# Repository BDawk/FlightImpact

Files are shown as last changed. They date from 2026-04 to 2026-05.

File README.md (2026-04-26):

# FlightImpact

A custom golf launch monitor combining computer vision (high-speed camera) with Doppler radar (HB100), targeting within 5% accuracy of industry standard launch monitors.

## Repository layout

```
flightimpact/
├── core/        Reusable algorithms, models, and API contract — ships in production
├── app/         Progressive Web App — runs on phone, tablet, desktop browser
├── devkit/      Dev kit code — Pi 5 services, Uno firmware, breadboard config
├── hardware/    Schematics, BOMs, 3D-printable mounts (currently dev kit only)
└── docs/        Architecture, setup, calibration, API reference
```

The rule: **`core/` and `app/` never import from `devkit/`.** When the production
hardware is ready, a new top-level folder will be created (`production/`) that also
imports from `core/`. The dev kit becomes one of multiple frontends to the same
algorithm core.

## Quick start (dev kit)

See [`docs/devkit_setup.md`](docs/devkit_setup.md) for the full guide. TL;DR:

```bash
# On the Raspberry Pi 5
cd devkit/pi
pip install -e ".[dev]"
python -m flightimpact_devkit.api

# In a separate terminal — build and serve the app
cd app
npm install
npm run dev
```

Then open `http://flightimpact.local:5173` from any device on the same network.

## Architecture

See [`docs/architecture.md`](docs/architecture.md).

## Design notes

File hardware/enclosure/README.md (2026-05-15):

# Enclosure (Second Pass)

This enclosure is now a horizontal rounded-rectangle chassis with:

- Side-by-side internal bays for battery + Pi 5 stack
- Pi 5 mounting on M2.5 heat-set insert bosses
- Top screen window + pocket + retention clamps
- PiSugar external interface holes (two button channels)
- External USB-C charging window
- Removable side service lid with 4x M3 screws

## Files

- `params.scad`: all tunable dimensions
- `base.scad`: main body
- `lid.scad`: removable service lid (print separately)
- `dock.scad`: legacy docking rail interface (disabled by default)

## Critical Tune-First Parameters

These are intentionally parameterized because exact modules vary by vendor revision:

- Screen:
  - `SCREEN_ACTIVE_W`, `SCREEN_ACTIVE_H`
  - `SCREEN_MODULE_W`, `SCREEN_MODULE_H`, `SCREEN_MODULE_T`
  - `SCREEN_POCKET_CLR`
- PiSugar button alignment:
  - `PISUGAR_BTN_Y`, `PISUGAR_BTN_Z1`, `PISUGAR_BTN_Z2`
  - `PISUGAR_BTN_HOLE_D`, `PISUGAR_BTN_GUIDE_ID`
- External charging breakout:
  - `CHARGE_PORT_W`, `CHARGE_PORT_H`, `CHARGE_PORT_X`, `CHARGE_PORT_Z`

## Pi Mounting / Inserts

Pi bosses are sized for M2.5 heat-set inserts:

- `PI_INSERT_OD`
- `PI_INSERT_DEPTH`
- `PI_BOSS_OD`

Recommended process:

1. Print only a small boss test coupon using your insert brand.
2. Confirm press-fit and melt depth.
3. Adjust `PI_INSERT_OD` in 0.1 mm increments as needed.

## Notes

- `ENABLE_DOCK = false` by default to keep the top surface dedicated to screen integration.
- If you need dock rails again, set `ENABLE_DOCK = true` in `params.scad`.

## Suggested Validation Workflow

1. Print a low-infill draft of `base.scad` at 0.28 mm layer height.
2. Dry-fit battery, Pi, PiSugar stack, and screen module.
3. Measure offsets and update only `params.scad`.
4. Reprint final with production wall/infill.

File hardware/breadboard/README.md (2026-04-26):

# HB100 amplifier — breadboard build

The HB100 produces a tiny IF signal — typically a few hundred microvolts to
a few millivolts. Before any ADC can sample it usefully, it needs ~60–80 dB
of gain plus high-pass filtering to get rid of the DC bias.

## Two-stage topology

```
         +---------------+        +---------------+
HB100 IF─┤ Stage 1       ├────────┤ Stage 2       ├──→ Line out
         │ LM358         │        │ TL072         │     (to ADC / sound card)
         │ Gain ≈ 100×   │        │ Gain ≈ 50×    │
         │ HPF fc=20 Hz  │        │ LPF fc=8 kHz  │
         +---------------+        +---------------+
         total gain ≈ 5000× (74 dB)
         passband ≈ 20 Hz – 8 kHz
```

The HPF in stage 1 removes the DC offset and 1/f noise. The LPF in stage 2
brick-walls the band of interest — golf Doppler returns sit between roughly
200 Hz (slow club approach) and 5500 Hz (driver ball flight).

## Component values

Pick values for non-inverting amplifier topology:
- **Stage 1 (LM358)**: Rf = 100k, Ri = 1k → gain = 101
  - HPF: input cap 1 µF + 8.2k bias resistor → fc ≈ 20 Hz
- **Stage 2 (TL072)**: Rf = 47k, Ri = 1k → gain = 48
  - LPF: feedback cap 470 pF across Rf → fc ≈ 7.2 kHz

## Power

Run the amps on a 9V battery, not the Pi 5V rail. The Pi rail is full of
switching noise that ends up in your audio band as a constant ~kHz hum.
Use a 78L05 to derive 5V for the HB100 itself, but keep the op-amp rails
isolated.

## Grounding

Star-ground at the battery negative. The HB100 ground, both op-amp grounds,
the output cable shield, and the bias network all return to the same physical
node. Don't daisy-chain.

## Shielding

The 10.525 GHz radiation from the HB100 will couple back into your amplifier
inputs if they're long traces on a breadboard. Keep stage-1 input wires under
2 cm. Once the rig works, build it on a small piece of perf board with a
ground plane underneath — this is the single biggest noise reduction you can
make.

## What to expect

With no target moving, you should see ~50 mV peak-to-peak of broadband noise
on a scope at the output. Wave your hand a foot away from the HB100 and you
should see a ~500 mV burst at a few hundred Hz. If you don't, check:
- HB100 powered from 5V (not 9V — it'll work but get hot)
- Op-amp pin 1 wired correctly (the LM358 pinout is non-obvious — pin 1 is
  output A, not input A)
- Battery actually connected (yes, this is the most common failure mode)

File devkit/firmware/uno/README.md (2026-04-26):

# Uno R3 firmware

The Uno acts as the dev kit's hardware-timing front-end:

| Pin  | Function |
|---|---|
| D8 | Hardware trigger output (5 V pulse, ~100 µs) — wire to camera shutter sync or strobe driver |
| D9 | LED strobe PWM output — wire to a MOSFET gate driving an LED array |
| D13  | Onboard heartbeat LED |

## Flashing

1. Open `uno.ino` in the Arduino IDE
2. Select board: **Arduino Uno**
3. Select port: the `/dev/ttyACM*` (Linux/macOS) or `COMx` (Windows) the Uno appears on
4. Click Upload

Or with `arduino-cli`:

```bash
arduino-cli compile --fqbn arduino:avr:uno uno.ino
arduino-cli upload  --fqbn arduino:avr:uno --port /dev/ttyACM0 uno.ino
```

## Testing without the Pi

Open a serial monitor at 115200 baud and try:

```
PING        -> PONG
ID          -> FLIGHTIMPACT-DEVKIT v0.1
TRIG        -> OK   (and you should see a pulse on D8)
STROBE 200  -> OK   (D9 HIGH for 200 ms)
STROBE OFF  -> OK
```

## Phase 2 plans

Replace the simple text protocol with a binary frame protocol that streams
HB100 IF samples to the Pi at 20 kHz. The header (`magic + n_samples`) is
already documented in `flightimpact_devkit/hal/hb100_radar.py::SerialRadar`.

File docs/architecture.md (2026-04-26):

# Architecture

FlightImpact splits cleanly into three layers: **algorithm core**, **device-side
services**, and **client app**. The core ships in both the dev kit and (eventually)
the production unit; the device services wrap the core in hardware-specific glue;
the app talks to the device over a versioned API contract.

## Repository layout in one paragraph

`core/` holds the reusable algorithms (radar DSP, ball detection, tracking,
spin extraction, ballistics), Pydantic data models, and the API contract.
`app/` is the React PWA — same code on phone, tablet, desktop browser. `devkit/`
contains everything that's specific to the dev-kit hardware: Pi 5 services
(`devkit/pi/`), Uno R3 firmware (`devkit/firmware/uno/`), and the Pi-only setup
scripts and systemd units. Hardware schematics and BOMs live in `hardware/`.
The dev kit imports from core; core never imports from the dev kit.

## Data flow — from photons to phone

1. The **HB100** emits a 10.525 GHz CW signal. Reflections from the clubhead
   and ball mix down to an audio-frequency IF signal proportional to radial
   velocity. The two-stage LM358 / TL072 amplifier brings this from microvolts
   to a clean line-level signal the Pi (or Uno) can sample.

2. The **camera** runs at 1080p120 in MJPEG, dumping frames to a userspace ring
   buffer in the camera service. The ring is sized to hold ~2 seconds of
   history so we have pre-impact frames available the moment a trigger fires.

3. The **radar service** continuously runs FFT on incoming sample blocks,
   extracts the dominant Doppler peak, and watches for a peak above the
   trigger threshold. When the clubhead approach pushes the speed estimate
   above ~30 mph (configurable), it fires a trigger callback.

4. The **processor service** receives the trigger, waits the post-trigger
   window for the ball to fly through frame, snapshots both the camera ring
   buffer and the radar sample buffer, and runs the analysis pipeline.

5. The pipeline runs ball detection → ball tracking → club detection →
   spin extraction → sensor fusion → ballistics simulation, producing a
   `ShotMetrics` object with per-metric confidence values.

6. Results are persisted to SQLite and pushed to all connected clients via
   the WebSocket as `ShotUpdated` messages. The same socket carries device
   status heartbeats, optional live camera previews, and optional radar
   spectrum frames for the dev waterfall view.

## Why this split

Three forces drove the structure:

**Hardware will change.** Production units will not use a USB camera or a
breadboard radar. By keeping algorithms in `core/` and hardware glue in
`devkit/pi/hal/`, the production firmware can implement the same `CameraSource`
and `RadarSource` protocols and reuse every line of algorithm code.

**The app should not know which device it's talking to.** Dev kit and
production unit speak the same versioned REST + WebSocket contract. Same PWA
build can target either.

**Iteration speed during development.** Python on the Pi means the entire
CV/DSP stack runs in one process with no marshaling — OpenCV, NumPy, SciPy,
Pydantic all native. When something is too slow, profile and selectively port
hot paths to C++ via pybind11 — don't rewrite the world up front.

## Connectivity model

The Pi runs in either of two modes, switchable at runtime:

- **AP mode (default)**: Pi creates its own Wi-Fi hotspot. Phone connects
  directly with no router involved. This is what you use at the range, in the
  backyard, anywhere with no infrastructure.
- **Client mode**: Pi joins an existing Wi-Fi network. Used at home for OTA
  updates and (later) cloud sync.

Both modes serve the app at `http://flightimpact.local:8000` via mDNS, so you
never type IP addresses.

## Versioning

The API contract is versioned in `core/api_contract/__init__.py`. Bumping
`API_VERSION` is a breaking-change signal for clients. The TypeScript types in
`app/src/lib/types.ts` are kept in sync by hand for now; the future plan is to
generate them from FastAPI's OpenAPI spec at build time.

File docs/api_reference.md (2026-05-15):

# API reference

The dev kit exposes a versioned REST + WebSocket API. The same contract will
be implemented by production firmware, so anything you build against this
will keep working.

Base URL: `http://flightimpact.local:8000` (or `http://192.168.4.1:8000` in
AP mode).

## REST endpoints

All paths under `/api/v1/`. Responses are JSON.

### `GET /api/v1/version`
Returns `{api_version, service}`. Use this for compatibility detection.

### `GET /api/v1/status`
Returns the current `DeviceStatus`. Same shape as the periodic WS heartbeat.

### `GET /api/v1/shots?limit=50&offset=0`
List recent shots, newest first.

### `GET /api/v1/shots/{id}`
Single shot by UUID. Returns `404` if not found.

### `POST /api/v1/shots/{id}/notes`
Body: `{notes?, club?}`. Update freeform notes or club tag for an existing
shot. Returns the updated `Shot`.

### `POST /api/v1/test/trigger`
Manually fire a test shot. Returns the shot stub immediately; the final
metrics arrive via WebSocket as the processor finishes. Dev-mode only —
returns `403` in production builds.

### `GET /api/v1/screen/state`
Returns the current on-device screen state snapshot (mode, health flags,
current shot summary, and UI header values).

### `POST /api/v1/screen/mode`
Body: `{mode}` where `mode` is one of `ScreenMode` values. Forces the on-device
screen into that mode. Dev-mode only.

### `POST /api/v1/screen/scenario`
Body: partial scenario payload to update screen state in one call:
`{mode?, boot_progress?, battery_pct?, session_id?, clock_hhmm?, brightness?, shot?}`.
Useful for mockup validation and live scenario testing. Dev-mode only.

## WebSocket

Connect to `/ws`. Messages flow in both directions.

### Server → client

Every message is a JSON object with a `type` discriminator. See
`core/models/telemetry.py` and `app/src/lib/types.ts` for full schemas.

| Type | When | Subscribe needed? |
|---|---|---|
| `device_status` | Every 2s + on-connect | No (default-on) |
| `shot_updated`  | Each transition (capturing → processing → complete) | No |
| `live_frame` | ~10 Hz JPEG preview | Yes |
| `radar_spectrum` | Per FFT block (~20 Hz) | Yes |
| `screen_state`  | On screen-state mutation (mode change, health, shot transition) | No (default-on) |
| `log` | Server log entries | Yes |

### Client → server

Plain text command frames, one per line:

| Command | Effect |
|---|---|
| `subscribe_live_frame` | Start receiving `live_frame` messages |
| `unsubscribe_live_frame` | Stop |
| `subscribe_radar_spectrum` | Start receiving `radar_spectrum` |
| `unsubscribe_radar_spectrum` | Stop |
| `subscribe_logs` | Start receiving `log` messages |
| `unsubscribe_logs` | Stop |
| `subscribe_screen_state` | Start receiving `screen_state` messages |
| `unsubscribe_screen_state` | Stop |

The default-off, opt-in pattern for high-bandwidth streams matters more than
it sounds: a phone on AP-mode Wi-Fi can saturate a 5 GHz link if you stream
1080p MJPEG to it continuously. The app subscribes only when the dev panel
mounts.

## Reconnection

The TypeScript socket client (`app/src/lib/transport/socket.ts`) handles
auto-reconnect with exponential backoff (1s → 8s cap) and replays any pending
subscription commands on each successful reconnect, so a brief Wi-Fi blip
doesn't require user intervention.

## Versioning

`API_VERSION` lives in `core/api_contract/__init__.py`. Bump it on any
breaking change. Clients should fetch `/api/v1/version` on connect and warn
if the major doesn't match.

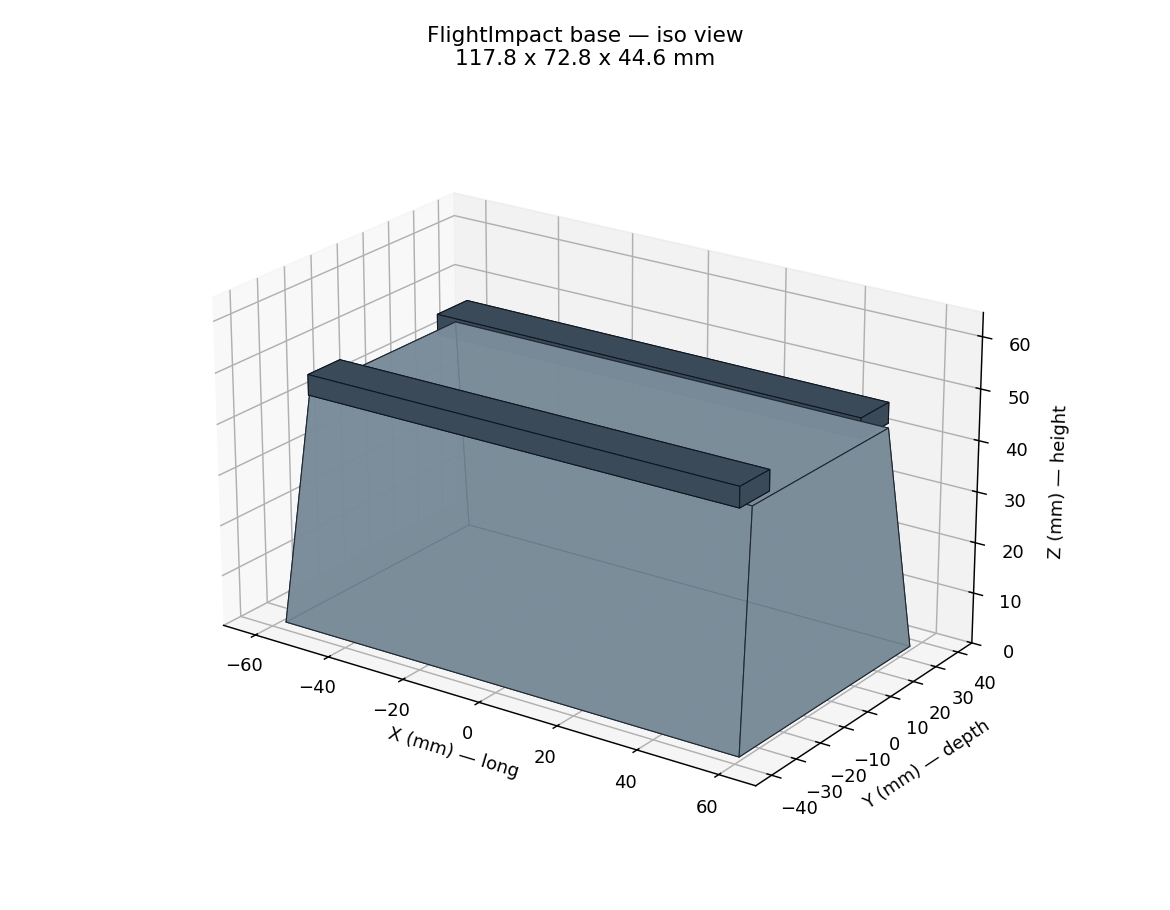
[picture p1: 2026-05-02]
hardware/enclosure/preview/preview_iso.png

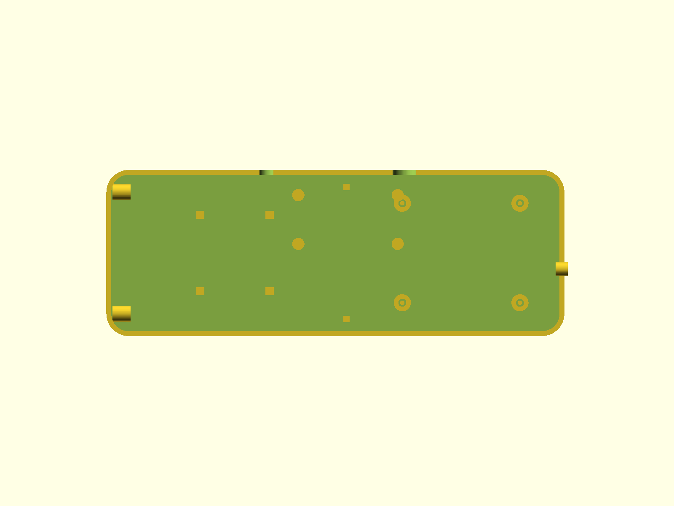
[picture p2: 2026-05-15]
hardware/enclosure/preview/base_top_new.png

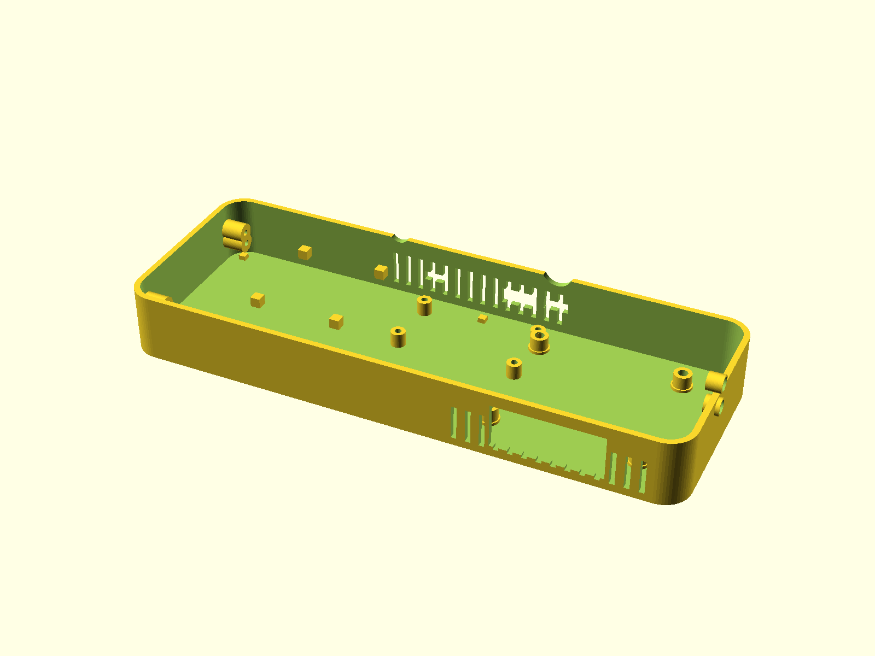
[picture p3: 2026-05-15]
hardware/enclosure/preview/base_default.png

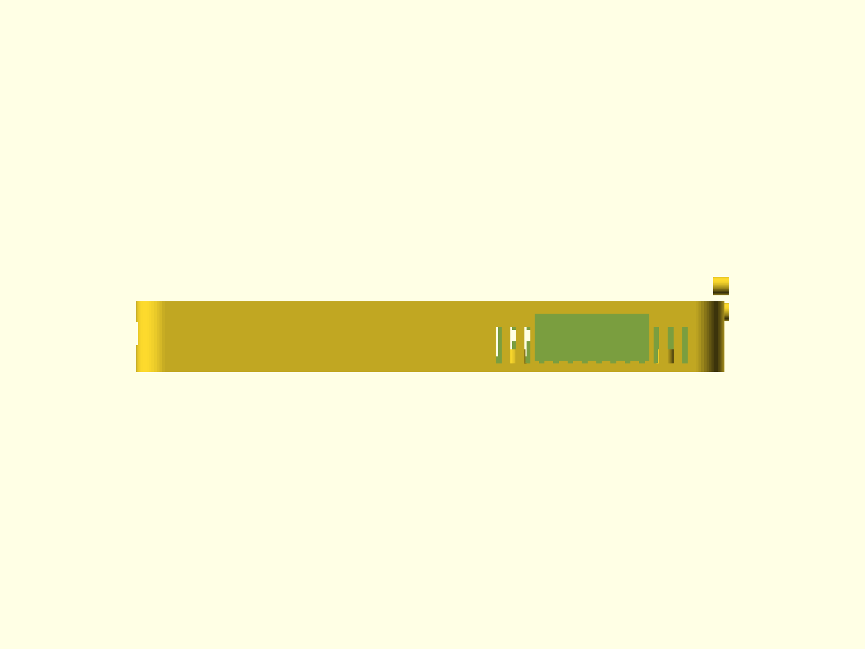
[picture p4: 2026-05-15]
hardware/enclosure/preview/base_front_new.png

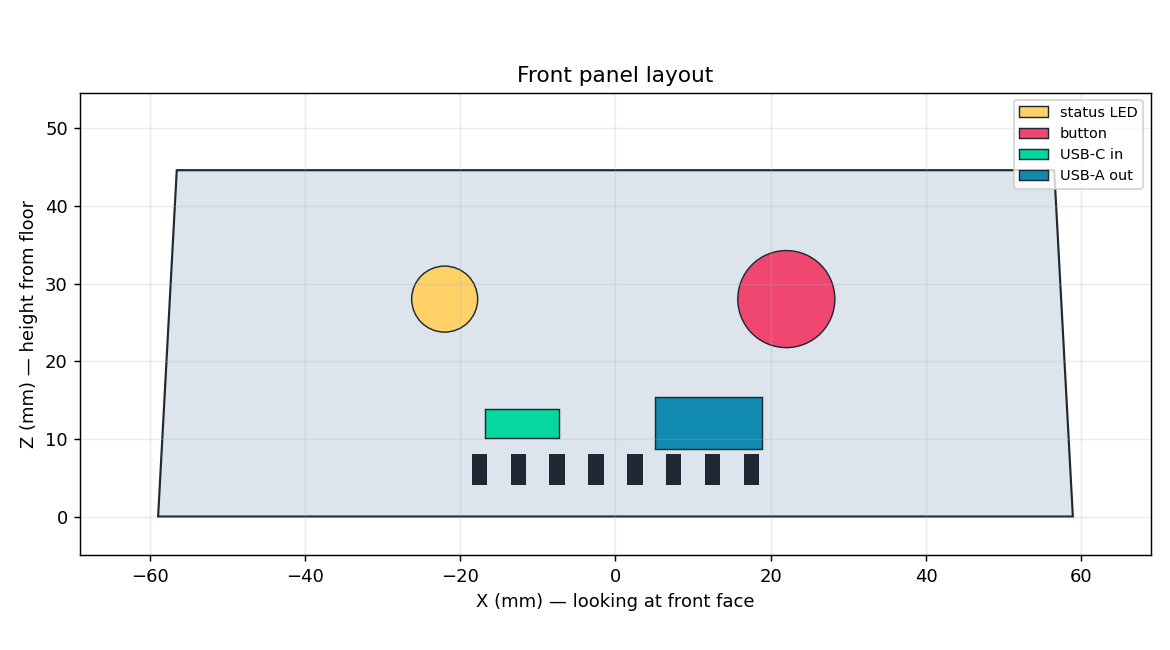
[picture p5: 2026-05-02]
hardware/enclosure/preview/preview_front.png

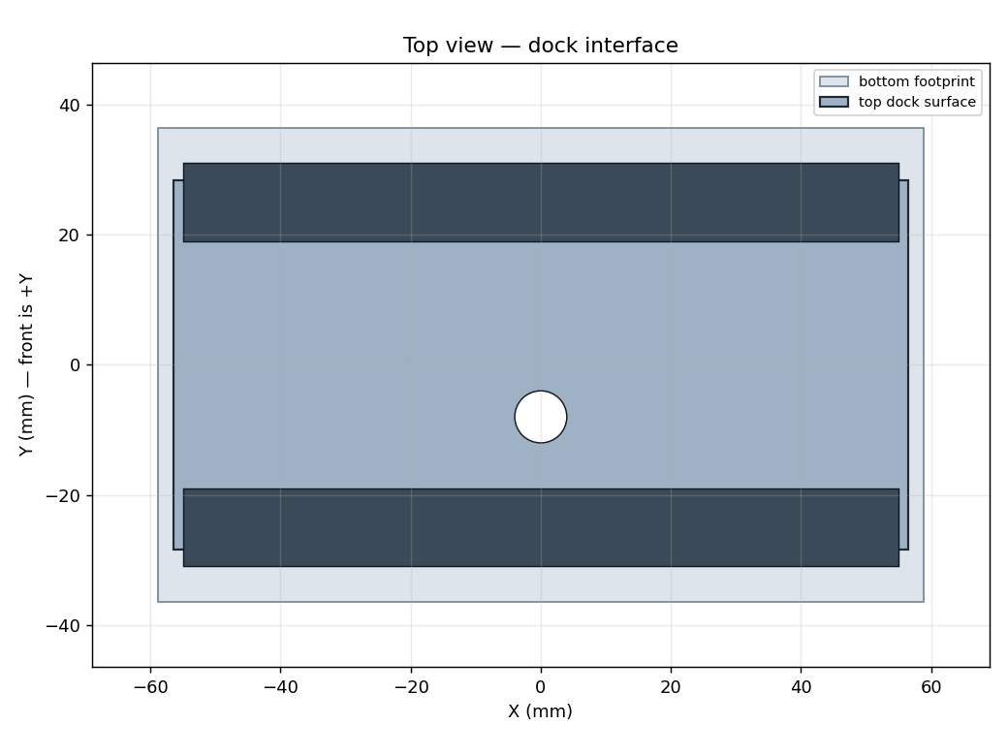
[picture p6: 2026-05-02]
hardware/enclosure/preview/preview_top.png

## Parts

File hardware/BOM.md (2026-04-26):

# Bill of materials — dev kit

Total target: ~$200–$300 in parts, plus the camera you already have.

## Compute

| Item | Qty | Notes |
|---|-----|---|
| Raspberry Pi 5 (4 GB) | 1 | 8 GB if you want headroom |
| Pi 5 active cooler | 1 | Required — Pi 5 throttles fast under sustained load |
| 27W USB-C PD power supply | 1 | The official Pi 5 supply, no substitutes |
| 32 GB A2 microSD | 1 | A2 rating matters — random IOPS during clip writes |
| Elegoo Uno R3 | 1 | Already on hand; trigger + strobe driver |

## Sensing

| Item | Qty | Notes |
|---|-----|---|
| HB100 module | 1 | $5–10 on Amazon / AliExpress |
| Camera (IFWATER 12MP IMX577 25° lens) | 1 | Already on hand |
| USB sound card (CM108-based) | 1 | Cheapest path to ADC for HB100 IF |

Future upgrade for production sensing: global-shutter sensor (Arducam AR0234
1200P or similar) — see `docs/architecture.md` for why.

## HB100 amplifier circuit

| Item | Qty | Notes |
|---|-----|---|
| LM358 dual op-amp DIP-8 | 1 | First stage |
| TL072 dual op-amp DIP-8 | 1 | Second stage (lower noise than LM358 here) |
| Resistors 1%: 10k, 100k, 1M | ~10 each | Gain-setting + biasing |
| Capacitors: 1µF, 10µF (electrolytic), 100nF (ceramic) | ~5 each | DC blocking + decoupling |
| 9V battery + clip | 1 | Cleaner than Pi 5V rail for analog front-end |
| Breadboard (full size, 830 tie-points) | 1 | |
| Jumper wire kit | 1 | M-M, M-F |

See `breadboard/` for the schematic and breadboard layout.

## Mounting + alignment

| Item | Qty | Notes |
|---|-----|---|
| Mini ball-head tripod (camera) | 1 | For repeatable camera positioning |
| Adjustable mount (HB100) | 1 | Doesn't need to be precise — angle calibration handles offset |
| Hitting mat (small turf square) | 1 | Reference position for the ball |
| Alignment laser (optional) | 1 | Cheap line laser makes setup repeatable |

## Cables

| Item | Qty | Notes |
|---|-----|---|
| USB-A to USB-A 2 m | 1 | Camera to Pi |
| USB-A to USB-B | 1 | Uno to Pi |
| 3.5mm TRS shielded | 1 | HB100 amp output to USB sound card line-in |

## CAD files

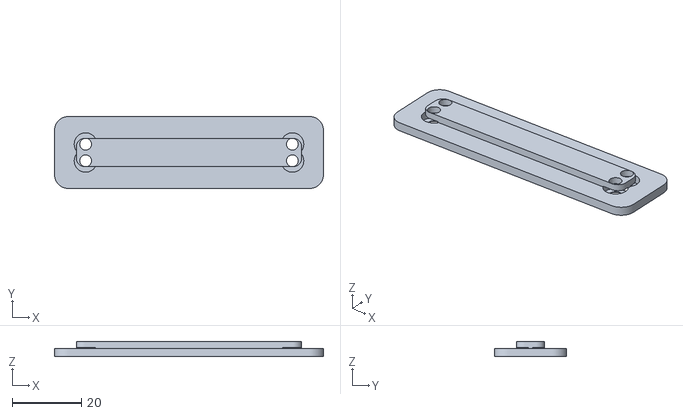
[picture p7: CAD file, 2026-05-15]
hardware/enclosure/lid.stl
77.8 x 20.8 x 4.40

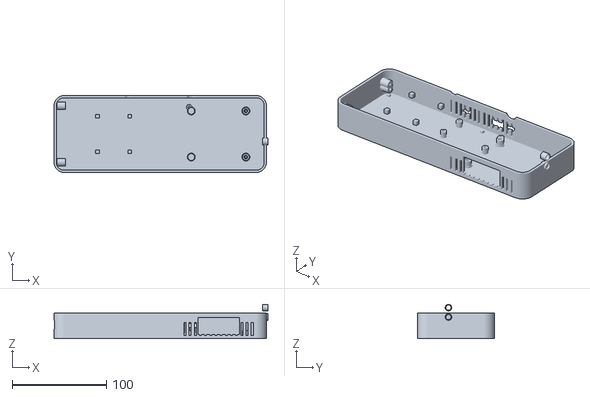
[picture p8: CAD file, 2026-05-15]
hardware/enclosure/base.stl
227.4 x 81.8 x 36.5

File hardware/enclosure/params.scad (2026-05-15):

// FlightImpact enclosure - central parameter file.
// All dimensions in mm.

/* PRINT + GLOBAL TOLERANCE */
$fn = 64;
PRINT_LAYER_H    = 0.2;
PRINT_NOZZLE     = 0.4;
WALL_T           = 2.4;
FLOOR_T          = 2.4;
LID_T            = 2.4;
M3_CLEAR         = 3.4;
M25_CLEAR        = 2.7;
CL_TIGHT         = 0.15;
CL_NORMAL        = 0.30;
CL_LOOSE         = 0.50;

/* RASPBERRY PI 5 */
PI_W             = 85.0;
PI_D             = 56.0;
PI_PCB_T         = 1.6;
PI_HOLE_DX       = 58.0;
PI_HOLE_DY       = 49.0;
PI_STANDOFF_H    = 5.2;
PI_TOP_CLR       = 14.0;

// M2.5 heat-set insert geometry (typical 3.5-4.0mm OD inserts)
PI_BOSS_OD           = 7.2;
PI_INSERT_OD         = 3.9;
PI_INSERT_DEPTH      = 4.8;
PI_INSERT_BOTTOM_WEB = 1.4;

/* BATTERY - single-cell LiPo pack */
BAT_W            = 110.0;
BAT_D            = 65.0;
BAT_H            = 12.0;
BAT_LEAD_LEN     = 60.0;
BAT_BAY_CL       = 1.5;

/* USB CHARGE/DISCHARGE BOARD */
USB_W            = 55.0;
USB_D            = 30.0;
USB_H            = 12.0;
USB_HOLE_DX      = 49.0;
USB_HOLE_DY      = 24.0;

/* STATUS LED / BUTTON */
LED_BEZEL_OD     = 8.5;
LED_NUT_OD       = 11.0;
LED_BODY_LEN     = 18.0;
BTN_HOLE_OD      = 12.5;
BTN_NUT_OD       = 15.0;
BTN_BODY_LEN     = 22.0;

/* SCREEN MODULE - Waveshare 1.69" ST7789V3 (tunable with calipers) */
SCREEN_ACTIVE_W      = 30.6;
SCREEN_ACTIVE_H      = 36.8;
SCREEN_WINDOW_CL     = 0.8;
SCREEN_WINDOW_W      = SCREEN_ACTIVE_W + SCREEN_WINDOW_CL;
SCREEN_WINDOW_H      = SCREEN_ACTIVE_H + SCREEN_WINDOW_CL;
SCREEN_MODULE_W      = 37.5;
SCREEN_MODULE_H      = 41.0;
SCREEN_MODULE_T      = 6.0;
SCREEN_POCKET_CLR    = 0.6;
SCREEN_POCKET_DEPTH  = 2.0;
SCREEN_CLAMP_W       = 4.0;
SCREEN_CLAMP_T       = 2.0;
SCREEN_CLAMP_DROP    = 4.0;

/* PISUGAR 3 PLUS (Pi 5 HAT) - envelope + externalized interface */
PISUGAR_W            = 88.0;
PISUGAR_D            = 58.0;
PISUGAR_H            = 11.5;
PISUGAR_SIDE_CLR     = 2.0;
PISUGAR_BTN_HOLE_D   = 5.2;   // for printed button plungers
PISUGAR_BTN_GUIDE_OD = 7.0;
PISUGAR_BTN_GUIDE_ID = 5.4;
PISUGAR_BTN_Z1       = 23.0;
PISUGAR_BTN_Z2       = 33.0;
PISUGAR_BTN_Y        = -8.0;

/* EXTERNAL CHARGING PORT (panel-mount USB-C breakout) */
CHARGE_PORT_W        = 10.2;
CHARGE_PORT_H        = 4.2;
CHARGE_PORT_X        = 34.0;
CHARGE_PORT_Z        = 14.0;

/* SIDE LID FASTENING */
LID_SCREW_D          = M3_CLEAR;
LID_SCREW_HEAD_D     = 6.6;
LID_SCREW_HEAD_H     = 2.2;
LID_BOSS_OD          = 8.0;
LID_BOSS_LEN         = 9.0;
LID_SCREW_PILOT_D    = 2.7;
LID_SCREW_EDGE_Y     = 11.0;
LID_SCREW_EDGE_Z     = 10.0;

/* OVERALL ENCLOSURE - horizontal rounded rectangle */
PI_GAP_ABOVE_BAT = 3.0;
COMP_GAP_X       = 14.0;
BAY_SIDE_CLR     = 6.0;
INSIDE_W         = BAT_W + PI_W + COMP_GAP_X + 2 * BAY_SIDE_CLR;
INSIDE_D         = max(BAT_D, PI_D) + 2 * BAY_SIDE_CLR;
INSIDE_H         = FLOOR_T + max(BAT_H + 6.0, PI_STANDOFF_H + PI_PCB_T + PI_TOP_CLR + 4.0);
BASE_W           = INSIDE_W + 2 * WALL_T;
BASE_D           = INSIDE_D + 2 * WALL_T;
BASE_H           = INSIDE_H;
BASE_R           = 11.0;
BASE_TAPER       = 0.0;  // kept for backward compatibility with preview script

BAT_CENTER_X     = -(PI_W/2 + COMP_GAP_X/2);
PI_CENTER_X      =  (BAT_W/2 + COMP_GAP_X/2);
BAT_CENTER_Y     = 0.0;
PI_CENTER_Y      = 0.0;
SCREEN_CENTER_X  = BAT_CENTER_X;
SCREEN_CENTER_Y  = 0.0;

/* FRONT/REAR FEATURE POSITIONS (X from center, Z from floor) */
FRONT_USBC_X     = -18.0;
FRONT_USBC_Z     =  13.0;
FRONT_USBA_X     =  18.0;
FRONT_USBA_Z     =  13.0;
FRONT_LED_X      = -34.0;
FRONT_LED_Z      =  30.0;
FRONT_BTN_X      =  34.0;
FRONT_BTN_Z      =  30.0;

/* SIDE LID */
LID_BORDER       = 8.0;
LID_CL           = CL_NORMAL;

/* VENTILATION */
VENT_SLOT_W      = 2.2;
VENT_SLOT_LEN    = 14.0;
VENT_SLOTS_N     = 14;
VENT_SLOT_PITCH  = 5.5;
VENT_BASE_Z      = 6.0;

/* DOCK INTERFACE (optional; legacy compatibility) */
ENABLE_DOCK      = false;
DOCK_RAIL_LEN    = BASE_W - 24.0;
DOCK_RAIL_GAP    = 50.0;
DOCK_RAIL_W      = 8.0;
DOCK_RAIL_H      = 4.0;
DOCK_RAIL_HEAD   = 12.0;
DOCK_RAIL_FILLET = 0.6;
DOCK_LATCH_W     = 14.0;
DOCK_LATCH_H     = 3.0;
DOCK_CABLE_OD    = 8.0;
DOCK_CL          = CL_NORMAL;

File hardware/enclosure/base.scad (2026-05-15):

// FlightImpact - base chassis (horizontal rounded rectangle).
//
// Coordinate system:
//   X = long axis (left/right)
//   Y = depth axis (front/back), +Y is front panel
//   Z = vertical, Z=0 at print bed
//
// Internal layout is side-by-side:
//   left bay  = LiPo battery
//   right bay = Raspberry Pi 5 on M2.5 insert standoffs
//
// One side face is opened as a removable lid window for service access.

include <params.scad>;
use <dock.scad>;

// ---------- 2D rounded rectangle ----------
module _rrect(w, d, r = BASE_R) {
    offset(r = r) offset(r = -r)
        square([w, d], center = true);
}

module _outer_shell() {
    linear_extrude(height = BASE_H)
        _rrect(BASE_W, BASE_D, BASE_R);
}

module _inner_cavity() {
    translate([0, 0, FLOOR_T])
        linear_extrude(height = BASE_H - FLOOR_T + 0.1)
            offset(delta = -WALL_T)
                _rrect(BASE_W, BASE_D, BASE_R);
}

// ---------- Front-panel cutouts ----------
CUT_DEPTH = WALL_T + 2.0;

module _front_panel_cutouts() {
    front_y = BASE_D / 2 + 0.1;

    translate([FRONT_LED_X, front_y, FRONT_LED_Z])
        rotate([90, 0, 0])
            cylinder(d = LED_BEZEL_OD + 2 * CL_TIGHT, h = CUT_DEPTH);

    translate([FRONT_BTN_X, front_y, FRONT_BTN_Z])
        rotate([90, 0, 0])
            cylinder(d = BTN_HOLE_OD + 2 * CL_TIGHT, h = CUT_DEPTH);

    translate([FRONT_USBC_X, front_y - CUT_DEPTH/2 + 0.1, FRONT_USBC_Z])
        cube([9.5, CUT_DEPTH, 3.8], center = true);

    translate([FRONT_USBA_X, front_y - CUT_DEPTH/2 + 0.1, FRONT_USBA_Z])
        cube([13.8, CUT_DEPTH, 6.7], center = true);

    for (i = [0:VENT_SLOTS_N - 1]) {
        x = -((VENT_SLOTS_N - 1) * VENT_SLOT_PITCH) / 2 + i * VENT_SLOT_PITCH;
        translate([x, front_y - CUT_DEPTH/2 + 0.1, VENT_BASE_Z + VENT_SLOT_LEN/2])
            cube([VENT_SLOT_W, CUT_DEPTH, VENT_SLOT_LEN], center = true);
    }
}

module _rear_panel_cutouts() {
    rear_y = -BASE_D / 2 - 0.1;
    // Pi 5 rear I/O window, centered on the Pi bay.
    translate([PI_CENTER_X, rear_y + CUT_DEPTH/2 - 0.1, FLOOR_T + 11])
        cube([44, CUT_DEPTH, 18], center = true);

    for (i = [0:VENT_SLOTS_N - 1]) {
        x = -((VENT_SLOTS_N - 1) * VENT_SLOT_PITCH) / 2 + i * VENT_SLOT_PITCH;
        translate([x + PI_CENTER_X, rear_y + CUT_DEPTH/2 - 0.1, BASE_H - 10 - VENT_SLOT_LEN/2])
            cube([VENT_SLOT_W, CUT_DEPTH, VENT_SLOT_LEN], center = true);
    }
}

module _top_screen_cutouts() {
    top_z = BASE_H + 0.1;
    // Visible window through top surface.
    translate([SCREEN_CENTER_X, SCREEN_CENTER_Y, top_z])
        cylinder(h = WALL_T + 0.6, d = 0.1); // anchor for transform preview stability
    translate([SCREEN_CENTER_X, SCREEN_CENTER_Y, BASE_H - WALL_T - 0.2])
        cube([SCREEN_WINDOW_W, SCREEN_WINDOW_H, WALL_T + 1.0], center = true);

    // Pocket for the display PCB/module body from the inside top.
    translate([SCREEN_CENTER_X, SCREEN_CENTER_Y, BASE_H - SCREEN_POCKET_DEPTH])
        cube([
            SCREEN_MODULE_W + SCREEN_POCKET_CLR,
            SCREEN_MODULE_H + SCREEN_POCKET_CLR,
            SCREEN_MODULE_T + 0.2
        ], center = true);
}

module _right_side_interface_cutouts() {
    side_x = BASE_W / 2 + 0.1;

    // External PiSugar button access holes (two function buttons).
    for (zv = [PISUGAR_BTN_Z1, PISUGAR_BTN_Z2])
        translate([side_x, PI_CENTER_Y + PISUGAR_BTN_Y, zv])
            rotate([0, 90, 0])
                cylinder(d = PISUGAR_BTN_HOLE_D, h = WALL_T + 2.0);

    // External charging USB-C window (front-right wall).
    front_y = BASE_D / 2 + 0.1;
    translate([CHARGE_PORT_X, front_y - CUT_DEPTH/2 + 0.1, CHARGE_PORT_Z])
        cube([CHARGE_PORT_W, CUT_DEPTH, CHARGE_PORT_H], center = true);
}

module _side_lid_window() {
    lid_w = BASE_D - 2 * LID_BORDER;
    lid_h = BASE_H - FLOOR_T - 2 * LID_BORDER;
    translate([-BASE_W/2 - 0.1, 0, FLOOR_T + LID_BORDER + lid_h/2])
        cube([WALL_T + 1.2, lid_w, lid_h], center = true);
}

module _side_lid_bosses() {
    y_span = BASE_D / 2 - LID_SCREW_EDGE_Y;
    z0 = FLOOR_T + LID_SCREW_EDGE_Z;
    z1 = BASE_H - LID_SCREW_EDGE_Z;
    x0 = -BASE_W / 2 + WALL_T + 0.6;

    for (yy = [-y_span, y_span], zz = [z0, z1])
        translate([x0, yy, zz])
            rotate([0, 90, 0])
                difference() {
                    cylinder(d = LID_BOSS_OD, h = LID_BOSS_LEN);
                    translate([0, 0, -0.05])
                        cylinder(d = LID_SCREW_PILOT_D, h = LID_BOSS_LEN + 0.1);
                }
}

module _feet_recesses() {
    foot_d = 12.5;
    foot_h = 1.2;
    inset = 12;
    for (sx = [-1, 1], sy = [-1, 1])
        translate([sx * (BASE_W/2 - inset), sy * (BASE_D/2 - inset), -0.01])
            cylinder(d = foot_d, h = foot_h);
}

module _battery_retainers() {
    rx = BAT_W / 2 + BAT_BAY_CL;
    ry = BAT_D / 2 + BAT_BAY_CL;
    h = 4.0;
    w = 3.0;

    for (sx = [-1, 1], sy = [-1, 1])
        translate([
            BAT_CENTER_X + sx * (rx - w/2),
            BAT_CENTER_Y + sy * (ry - w/2),
            FLOOR_T,
        ])
            cube([w, w, h], center = true);
}

module _screen_clamps() {
    // Printed clamp tabs that lightly retain the screen PCB from inside.
    y0 = SCREEN_CENTER_Y + (SCREEN_MODULE_H + SCREEN_POCKET_CLR)/2 - SCREEN_CLAMP_W/2;
    y1 = SCREEN_CENTER_Y - (SCREEN_MODULE_H + SCREEN_POCKET_CLR)/2 + SCREEN_CLAMP_W/2;
    x0 = SCREEN_CENTER_X + (SCREEN_MODULE_W + SCREEN_POCKET_CLR)/2 - SCREEN_CLAMP_W/2;
    x1 = SCREEN_CENTER_X - (SCREEN_MODULE_W + SCREEN_POCKET_CLR)/2 + SCREEN_CLAMP_W/2;
    zc = BASE_H - SCREEN_POCKET_DEPTH - SCREEN_CLAMP_DROP/2;

    for (xx = [x0, x1], yy = [y0, y1])
        translate([xx, yy, zc])
            cube([SCREEN_CLAMP_W, SCREEN_CLAMP_W, SCREEN_CLAMP_DROP], center = true);
}

module _pi_insert_boss() {
    difference() {
        cylinder(d = PI_BOSS_OD, h = PI_STANDOFF_H);
        // Heat-set insert cavity from top face.
        translate([0, 0, PI_STANDOFF_H - PI_INSERT_DEPTH])
            cylinder(d = PI_INSERT_OD, h = PI_INSERT_DEPTH + 0.05);
        // Keep a narrow pilot below insert to avoid elephant-foot bulge.
        translate([0, 0, -0.05])
            cylinder(d = 2.2, h = PI_STANDOFF_H - PI_INSERT_DEPTH + PI_INSERT_BOTTOM_WEB);
    }
}

module _pi_mounts() {
    z0 = FLOOR_T;
    for (sx = [-1, 1], sy = [-1, 1]) {
        x = PI_CENTER_X + sx * PI_HOLE_DX / 2;
        y = PI_CENTER_Y + sy * PI_HOLE_DY / 2;
        // Pedestal from floor to board plane.
        translate([x, y, z0])
            cylinder(d = PI_BOSS_OD + 1.2, h = 1.2);
        // Insert boss at board plane.
        translate([x, y, z0 + 1.2])
            _pi_insert_boss();
    }
}

module _usb_posts() {
    post_h = 6.0;
    post_od = 6.0;
    usb_center_x = (BAT_CENTER_X + PI_CENTER_X) / 2;
    usb_center_y = BASE_D/2 - WALL_T - USB_D/2 - 7;

    for (sx = [-1, 1], sy = [-1, 1]) {
        x = usb_center_x + sx * USB_HOLE_DX / 2;
        y = usb_center_y + sy * USB_HOLE_DY / 2;
        translate([x, y, FLOOR_T])
            difference() {
                cylinder(d = post_od, h = post_h);
                translate([0, 0, -0.05]) cylinder(d = M25_CLEAR, h = post_h + 0.1);
            }
    }
}

module _pisugar_button_guides() {
    side_x = BASE_W/2 - WALL_T - 2.0;
    for (zv = [PISUGAR_BTN_Z1, PISUGAR_BTN_Z2])
        translate([side_x, PI_CENTER_Y + PISUGAR_BTN_Y, zv])
            rotate([0, 90, 0])
                difference() {
                    cylinder(d = PISUGAR_BTN_GUIDE_OD, h = 6.0);
                    translate([0, 0, -0.05])
                        cylinder(d = PISUGAR_BTN_GUIDE_ID, h = 6.1);
                }
}

// ============================================================================
//  Main base
// ============================================================================
module base_chassis() {
    union() {
        difference() {
            union() {
                _outer_shell();
                if (ENABLE_DOCK)
                    translate([0, 0, BASE_H]) rotate([0, 0, 90]) dock_male();
            }
            _inner_cavity();
            _front_panel_cutouts();
            _rear_panel_cutouts();
            _top_screen_cutouts();
            _right_side_interface_cutouts();
            _side_lid_window();
            _feet_recesses();
        }

        _battery_retainers();
        _pi_mounts();
        _usb_posts();
        _screen_clamps();
        _pisugar_button_guides();
        _side_lid_bosses();
    }
}

// ---------- Render ----------
base_chassis();

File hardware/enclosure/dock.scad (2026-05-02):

// FlightImpact — top-of-base DOCK INTERFACE.
//
// Two parallel T-rails run along the long axis. A camera/radar/etc module
// slides onto the dock from the rear and clicks into a finger-release latch.
//
// The dock is intentionally exposed as TWO modules:
//   dock_male()    — the rails as POSITIVE geometry (added to the base shell)
//   dock_female()  — the matching slot as NEGATIVE geometry (subtracted from
//                    a module's underside)
// This guarantees the mating fit is parametrically symmetric — change a
// dimension in params.scad and both sides update together.

include <params.scad>;

// ---------- Single T-rail ----------
module _t_rail(length) {
    // rail base
    translate([-DOCK_RAIL_W/2, 0, 0])
        cube([DOCK_RAIL_W, length, DOCK_RAIL_H * 0.6]);
    // rail head (the T cap, wider at top so the slot retains it laterally)
    translate([-DOCK_RAIL_HEAD/2, 0, DOCK_RAIL_H * 0.6])
        cube([DOCK_RAIL_HEAD, length, DOCK_RAIL_H * 0.4]);
}

// ---------- Negative slot to receive a single T-rail ----------
module _t_slot(length) {
    // base channel, slightly wider for sliding fit
    translate([-(DOCK_RAIL_W + 2*DOCK_CL)/2, 0, 0])
        cube([DOCK_RAIL_W + 2*DOCK_CL, length, DOCK_RAIL_H * 0.6 + DOCK_CL]);
    // head undercut
    translate([-(DOCK_RAIL_HEAD + 2*DOCK_CL)/2, 0, DOCK_RAIL_H * 0.6 + DOCK_CL])
        cube([DOCK_RAIL_HEAD + 2*DOCK_CL, length, DOCK_RAIL_H * 0.4 + DOCK_CL]);
}

// ---------- Latch tab (positive, sits at front end of dock) ----------
module _latch_tab() {
    // a small ramp tab — module's matching pocket clicks over it
    hull() {
        translate([-DOCK_LATCH_W/2, 0, 0])
            cube([DOCK_LATCH_W, 0.5, DOCK_LATCH_H]);
        translate([-DOCK_LATCH_W/2, 5, 0])
            cube([DOCK_LATCH_W, 0.5, 0.5]);
    }
}

// ---------- Public: positive dock geometry (added to base top) ----------
// Place in PARENT coordinates so that origin = top-center of base, +Y = rear.
module dock_male() {
    // two T-rails, symmetric about Y axis
    for (sx = [-1, 1]) translate([sx * DOCK_RAIL_GAP/2, -DOCK_RAIL_LEN/2, 0])
        _t_rail(DOCK_RAIL_LEN);
    // front-edge latch tab
    translate([0, -DOCK_RAIL_LEN/2 - 0.001, 0]) _latch_tab();
    // cable pass-through stub (a small chimney that the module can route into)
    difference() {
        translate([0, -DOCK_CABLE_OD, 0])
            cylinder(d = DOCK_CABLE_OD + 4, h = 1.2);
        translate([0, -DOCK_CABLE_OD, -0.1])
            cylinder(d = DOCK_CABLE_OD, h = 2.0);
    }
}

// ---------- Public: matching female slot for a module's underside ----------
// Subtract this from the bottom of any module that should snap onto the dock.
module dock_female() {
    for (sx = [-1, 1]) translate([sx * DOCK_RAIL_GAP/2, -DOCK_RAIL_LEN/2, 0])
        _t_slot(DOCK_RAIL_LEN + DOCK_CL);
    // latch pocket
    translate([0, -DOCK_RAIL_LEN/2 - 0.5, 0])
        cube([DOCK_LATCH_W + 2*DOCK_CL, 6, DOCK_LATCH_H + DOCK_CL], center = false);
    // cable pass-through hole
    translate([0, -DOCK_CABLE_OD, -0.1])
        cylinder(d = DOCK_CABLE_OD + 2*DOCK_CL, h = 50);
}

// ---------- Self-test render ----------
// Comment this out when use<>ing the file from base.scad.
if ($preview) {
    color("DimGray") dock_male();
    color("Tomato", 0.4) translate([0, 0, 30]) dock_female();
}

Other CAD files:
hardware/enclosure/lid.scad

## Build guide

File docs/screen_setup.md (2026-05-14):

# Dev kit screen — Waveshare 1.69" ST7789V3 LCD

The dev kit has an on-device screen so you can read shot results without
pulling out your phone. The panel is a Waveshare 1.69" rounded-corner IPS
(240 × 280, ST7789V3), driven over SPI from the Pi.

The mockups in [`devkit/screen-mockups/index.html`](../devkit/screen-mockups/index.html)
are rendered at native resolution and show every state the screen can be in.

## Pinout — Pi 5 ↔ ST7789V3

Labels vary between breakouts. The columns below list the most common
variants — match whatever's silkscreened on your panel to the same row.

| Panel labels | Pi GPIO | Pi physical pin | Notes |
|---|---|---|---|
| VCC | 3.3 V | 1 | Don't use 5 V — the panel is 3.3 V only |
| GND | GND | 6 | |
| **SDA** / DIN / MOSI / SDI / SI | GPIO 10 | 19 | SPI0 MOSI. "SDA" here means serial data — these panels are SPI, not I²C |
| **SCL** / SCK / CLK / SCLK | GPIO 11 | 23 | SPI0 SCLK |
| **RES** / RST / RESET | GPIO 27 | 13 | Reset |
| **DC**  / A0 / D/C | GPIO 25 | 22 | Data / command select |
| **CS**  / CE / SS | GPIO 8  | 24 | SPI0 CE0. Some 7-pin boards omit this — see note below |
| **BLK** / BL / LED / LITE | GPIO 18 | 12 | Backlight, hardware PWM for dimming |

If your board only exposes 7 pins (no CS broken out), CS is hardwired low
on the PCB. Don't wire anything to Pi GPIO 8 in that case — the driver
works either way because the panel always thinks it's selected.

The pin choices avoid the rest of the dev kit: I²C (GPIO 2/3) is free for
future sensors, UART (GPIO 14/15) is free, GPIO 4 stays free for 1-Wire
temperature probes, and the audio HAT (if you add one) still has its
expected pins. The 9V op-amp board has its own battery — no Pi pins touched.

## Enable SPI

On Pi OS Bookworm, SPI is off by default. One-time setup:

```bash
sudo raspi-config nonint do_spi 0   # enables SPI without the curses UI
sudo reboot
```

After reboot, confirm:

```bash
ls /dev/spidev0.*        # expect /dev/spidev0.0 and /dev/spidev0.1
```

The screen driver uses `spidev0.0` (CE0).

## Python dependencies

The driver uses `spidev` for SPI and `gpiozero` (with the `lgpio` backend
that ships on Pi 5) for the DC / RST / BL pins, plus Pillow for rendering.

```bash
cd /opt/flightimpact
source venv/bin/activate
pip install spidev gpiozero lgpio Pillow
```

`lgpio` is what makes this work on Pi 5 — `RPi.GPIO` does NOT work on Pi 5.

## Smoke test

Once wired, run the smoke test to confirm the panel is alive before any UI
code touches it. The user needs to be in the `gpio` and `spi` groups (default
on Pi OS — `groups` to check). Run from the venv, no sudo:

```bash
cd /opt/flightimpact && source venv/bin/activate
python -m flightimpact_devkit.scripts.test_screen
```

If you need sudo for any reason (e.g. groups not set up yet), call the venv's
Python directly so the package is on the path:

```bash
sudo /opt/flightimpact/venv/bin/python -m flightimpact_devkit.scripts.test_screen
```

You should see, in order, ~1 second each:

1. Solid red, green, blue (sanity check for color order)
2. White, then black
3. Four 70-px corner squares — confirms orientation and that the rounded
   corner mask isn't clipping content
4. A diagonal gradient — confirms full 16-bit color depth

If you see colors but they're swapped (red where blue should be), the BGR
flag is wrong — pass `--bgr` to the test script. If the image is rotated
90°, pass `--rotate 90`.

## Common wiring problems

- **Nothing on screen, backlight is on.** SPI almost certainly isn't enabled
  (`ls /dev/spidev0.*` shows nothing). Re-run `raspi-config` and reboot.
- **Nothing on screen, backlight off.** BL wire not connected — the panel
  defaults to BL off. Connect BL to GPIO 18 (or any 3.3 V rail for a quick test).
- **Garbled / shifted image with visible offset on the left.** This is the
  classic 1.69" symptom — the driver is set to the 240×240 variant. The
  HAL handles this with column/row offsets of (0, 20); make sure you're on
  the latest `hal/st7789.py`.
- **Tearing / partial frames.** Drop `spi_hz` in the config from 40 MHz
  to 24 MHz. Most Pi 5 setups are fine at 40 MHz, but long jumper wires
  start to fail above ~30 MHz.

## Integrating with the API service

The screen service is wired into the same lifespan as camera and radar in
[`services/api/app.py`](../devkit/pi/flightimpact_devkit/services/api/app.py).
If no SPI panel is detected, it falls back to a `MockDisplay` that just
discards frames — so dev work on a laptop without hardware still runs cleanly.

To watch what's being drawn without a screen connected, set
`FLIGHTIMPACT_SCREEN_SNAPSHOT_DIR=/tmp/screen` and the mock display writes
each frame as a PNG. Useful for designing new screens.

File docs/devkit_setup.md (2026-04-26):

# Dev kit setup

This guide walks through standing up a full FlightImpact dev kit from a fresh
Raspberry Pi 5. End state: you fire a trigger from the app, the device captures
a clip + radar samples, and metrics show up in the app within a second.

## What you need

**Hardware**
- Raspberry Pi 5 (4 GB or 8 GB)
- 32 GB+ A2-rated microSD card
- Official Pi 5 27W USB-C PD power supply
- USB camera (the IFWATER 12MP IMX577 / 25° lens or equivalent)
- HB100 Doppler radar module
- Two-stage op-amp board (LM358 or TL072) — see `hardware/breadboard/`
- USB sound card *or* MCP3008-on-SPI ADC for sampling the HB100 IF
- Elegoo Uno R3 (for trigger output and LED strobe driving — Phase 1.5+)
- A laptop or phone for the app

**Software on the Pi**
- Raspberry Pi OS Bookworm (64-bit, "Lite" is fine — no desktop needed)
- Python 3.11 or newer (Bookworm ships 3.11)
- Node.js 20+ (only needed if building the app on the Pi; usually you build on
  your laptop and `scp` the `dist/` folder over)

## First-boot setup

```bash
# Update the system
sudo apt update && sudo apt upgrade -y

# Required system packages
sudo apt install -y python3-venv python3-pip git \
                    libopencv-dev v4l-utils \
                    avahi-daemon network-manager
```

## Pull the code

```bash
sudo mkdir -p /opt/flightimpact
sudo chown $USER:$USER /opt/flightimpact
cd /opt
git clone <your-repo-url> flightimpact
cd flightimpact
```

## Set up the Pi as a Wi-Fi access point

So you can connect from your phone anywhere, no router needed:

```bash
sudo ./devkit/pi/scripts/setup_ap_mode.sh "FlightImpact-Dev" "myStrongPass"
sudo ./devkit/pi/scripts/setup_mdns.sh flightimpact
```

After this:
- A new Wi-Fi network "FlightImpact-Dev" appears
- Connecting your phone gets you an IP on `192.168.4.0/24`
- The Pi is reachable at `flightimpact.local`

## Install and start the API service

```bash
sudo ./devkit/pi/scripts/install_services.sh /opt/flightimpact
```

This script:
1. Creates a `flightimpact` system user
2. Sets up `/var/lib/flightimpact/` (database + clips) and `/var/log/flightimpact/`
3. Creates a venv at `/opt/flightimpact/venv` and installs `core/` and `devkit/pi/`
4. Installs and enables the `flightimpact-api` systemd unit

Verify it's running:

```bash
systemctl status flightimpact-api
journalctl -u flightimpact-api -f
```

You should see lines like `Camera service started`, `Radar service started`,
`Storage opened`, and `Uvicorn running on http://0.0.0.0:8000`.

If no camera / radar is connected, the service falls back to mock sources and
still starts cleanly — useful for app development without the rig set up.

## Build and serve the app

On your laptop (where Node is installed):

```bash
cd app
npm install
npm run build
```

Then either:

**Option A — serve via Python on the Pi** (no Node needed on the Pi):

```bash
# On your laptop, after building:
scp -r dist/* pi@flightimpact.local:/opt/flightimpact/app/dist/

# On the Pi:
cd /opt/flightimpact/app/dist
python3 -m http.server 5173 --bind 0.0.0.0
```

**Option B — dev mode on your laptop, talking to the Pi**:

```bash
# In app/.env.local:
VITE_API_HOST=http://flightimpact.local:8000

npm run dev
# Open http://localhost:5173
```

## Open the app on your phone

1. Connect your phone to the `FlightImpact-Dev` Wi-Fi
2. Open Safari/Chrome and go to `http://flightimpact.local:5173`
3. Tap "Add to Home Screen" — it installs as a PWA and looks like an app

You should see a green Online pill in the header. The status row shows
camera + radar connection state. Hit the **Test shot** button to fire a manual
trigger and verify the round-trip works.

## Calibrate

See [`calibration.md`](calibration.md). Short version:

1. Print a 9x6 checkerboard and tape it to a flat surface
2. From the Settings tab → Calibration → "Start camera calibration", capture
   ~15 frames of the board at varied angles
3. Set up the radar at the firing position, point it down-range, and hit
   "Calibrate radar zero" — this learns the cosine angle correction

## Wiring up the Uno (optional Phase 1.5)

The Uno provides a hardware trigger output and an LED strobe driver. Wire it:

| Uno pin | Function | Connect to |
|---|---|---|
| D8 | 5 V trigger pulse | Camera GPIO trigger or strobe FET |
| D9 | Strobe PWM (5 V) | LED array gate driver |
| GND | Common ground | Strobe ground, camera ground |
| USB | Power + data | Pi USB port |

Flash `devkit/firmware/uno/uno.ino` from the Arduino IDE. The Pi will
auto-detect the Uno on `/dev/ttyACM0` once the radar service supports it
(Phase 1.5).

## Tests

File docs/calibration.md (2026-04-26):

# Calibration

Two things need calibration before metrics will be accurate to within 5%:

1. **Camera intrinsics** — focal length, principal point, lens distortion
2. **Radar speed coefficient** — the cosine-angle correction from the look angle

Both are persisted in SQLite as JSON blobs and loaded at service startup.

## Camera calibration

We use OpenCV's standard checkerboard routine. The dev kit ships with a UI
wizard at Settings → Calibration → Camera; this section explains what's
happening behind it.

**Print pattern.** Standard 9x6 inner-corner checkerboard with 25 mm squares.
Tape it flat to a piece of foam board or hardback book. Glossy paper introduces
glare — matte print is much better.

**Capture.** Hold the board roughly where the ball will sit. Move it through
~15 different orientations: tilted left, right, forward, back, rotated, near,
far. The wizard accepts a frame each time it detects all 54 corners cleanly,
then refuses duplicates that are too similar to ones it already has.

**Solve.** Once 15+ valid frames are captured, the wizard runs
`cv2.calibrateCamera()` and produces an intrinsic matrix + distortion
coefficients. These are stored as a `CameraCalibration`.

**Sanity check.** A well-calibrated 25° M12 lens at 1080p should give you:
- `fx ≈ fy ≈ 4400` pixels (close, since fx and fy should match for square pixels)
- `cx ≈ 960`, `cy ≈ 540` (within ~30 px of image center)
- `|k1| < 0.3` and the rest near zero (the 25° lens is "low distortion" by spec)

Big deviations point to a bad capture set — re-shoot.

## Camera extrinsics — where the camera sits relative to the ball

For launch-side measurement we need to know:
- distance from camera to ball (mm)
- height of camera above ball (mm)
- side offset (mm)
- yaw and pitch of the camera relative to the ball-to-target line

The wizard asks for these as direct measurements (tape measure / digital level).
A future improvement is auto-extrinsic-extraction by placing the checkerboard
exactly where the ball will be and solving for the camera pose from the same
calibration session.

The derived `mm_per_pixel` at the ball plane is what we use to convert pixel
displacements between frames into real-world ball speed. This is the link
between camera measurements and the radar — they should agree, and any
disagreement is what fusion catches.

## Radar calibration

The textbook coefficient for an HB100 at 10.525 GHz is
**0.03187 mph per Hz** of Doppler shift. That's true only if the radar is
pointed exactly at the ball's flight direction. In a real launch-side install,
the radar sits a few feet to the side, and the cosine of that angle scales
the apparent speed.

**Procedure.** Use a known-speed reference — a ball thrown by hand isn't
precise enough; better is a tennis-ball machine or, ideally, your reference
launch monitor on the same shot. Take 10 shots with both the FlightImpact dev
kit and the reference monitor logging. The wizard fits the linear coefficient
that minimizes error against the reference, then writes it into the
`RadarCalibration.speed_per_hz_mph` field.

If you have no reference monitor handy, point the radar directly along the
firing line and use the textbook coefficient — it'll be accurate to within
a few percent for shots that fly close to that line.

## How often to re-calibrate

- **Camera intrinsics**: once per camera. Stable forever unless you change the
  lens or take a hard knock to the assembly.
- **Camera extrinsics**: every time you set the rig up. The whole point of
  the dev kit is portability, so the geometry changes every session.
- **Radar coefficient**: per-installation. Once you've got the radar mount
  finalized, it's stable.

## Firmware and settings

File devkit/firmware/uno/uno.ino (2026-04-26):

/*
 * FlightImpact dev kit — Uno R3 firmware
 *
 * Roles (Phase 1):
 *   - LED strobe driver on D9 (PWM)
 *   - Hardware trigger pulse output on D8 (digital, ~5us)
 *   - Heartbeat LED on D13
 *   - Listens on serial (115200 baud) for commands from the Pi
 *
 * Future roles (Phase 2+):
 *   - ADC sampler streaming HB100 IF samples to Pi at 20 kHz
 *
 * Serial protocol (text-based, line-terminated):
 *   "PING\n"            -> "PONG\n"
 *   "TRIG\n"            -> fire trigger pulse, reply "OK\n"
 *   "STROBE <ms>\n"     -> turn on strobe for <ms> milliseconds
 *   "STROBE OFF\n"      -> strobe off
 *   "ID\n"              -> reply "FLIGHTIMPACT-DEVKIT v0.1\n"
 *
 * Frame format (when streaming samples in Phase 2):
 *   0xAA 0x55 [n_lo n_hi] [n samples * 2 bytes int16 LE]
 */

#include <Arduino.h>

constexpr uint8_t PIN_TRIGGER = 8;
constexpr uint8_t PIN_STROBE  = 9;
constexpr uint8_t PIN_HEARTBEAT = 13;
constexpr uint16_t TRIGGER_PULSE_US = 100;

uint32_t lastHeartbeat = 0;
uint32_t strobeUntil = 0;

void setup() {
  Serial.begin(115200);
  pinMode(PIN_TRIGGER, OUTPUT);
  pinMode(PIN_STROBE, OUTPUT);
  pinMode(PIN_HEARTBEAT, OUTPUT);
  digitalWrite(PIN_TRIGGER, LOW);
  analogWrite(PIN_STROBE, 0);

  // Quick self-test blink so we know it booted
  for (int i = 0; i < 3; i++) {
    digitalWrite(PIN_HEARTBEAT, HIGH);
    delay(80);
    digitalWrite(PIN_HEARTBEAT, LOW);
    delay(80);
  }
}

void firePulse() {
  digitalWrite(PIN_TRIGGER, HIGH);
  delayMicroseconds(TRIGGER_PULSE_US);
  digitalWrite(PIN_TRIGGER, LOW);
}

void handleCommand(const String& cmd) {
  if (cmd == "PING") {
    Serial.println("PONG");
  } else if (cmd == "TRIG") {
    firePulse();
    Serial.println("OK");
  } else if (cmd.startsWith("STROBE ")) {
    String arg = cmd.substring(7);
    if (arg == "OFF") {
      analogWrite(PIN_STROBE, 0);
      strobeUntil = 0;
    } else {
      uint32_t ms = arg.toInt();
      if (ms > 0 && ms < 5000) {
        analogWrite(PIN_STROBE, 255);
        strobeUntil = millis() + ms;
      }
    }
    Serial.println("OK");
  } else if (cmd == "ID") {
    Serial.println("FLIGHTIMPACT-DEVKIT v0.1");
  } else {
    Serial.print("ERR Unknown: ");
    Serial.println(cmd);
  }
}

String inputBuffer;

void loop() {
  // Heartbeat LED — 1 Hz blink
  uint32_t now = millis();
  if (now - lastHeartbeat > 500) {
    digitalWrite(PIN_HEARTBEAT, !digitalRead(PIN_HEARTBEAT));
    lastHeartbeat = now;
  }

  // Strobe auto-off
  if (strobeUntil > 0 && now >= strobeUntil) {
    analogWrite(PIN_STROBE, 0);
    strobeUntil = 0;
  }

  // Serial command parsing
  while (Serial.available() > 0) {
    char c = Serial.read();
    if (c == '\n' || c == '\r') {
      if (inputBuffer.length() > 0) {
        handleCommand(inputBuffer);
        inputBuffer = "";
      }
    } else {
      inputBuffer += c;
      if (inputBuffer.length() > 64) {
        inputBuffer = "";  // overflow protection
      }
    }
  }
}

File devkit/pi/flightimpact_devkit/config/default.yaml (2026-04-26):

camera:
  device: /dev/video0
  width: 1920
  height: 1080
  fps: 120
  pixel_format: MJPG
  buffer_seconds: 2.0

radar:
  serial_port: /dev/ttyACM0
  baud_rate: 115200
  sample_rate_hz: 20000
  fft_size: 1024
  use_pi_adc: true
  audio_device: default

trigger:
  source: radar
  radar_speed_threshold_mph: 30.0
  pre_trigger_ms: 200
  post_trigger_ms: 1500

network:
  ap_mode: true
  ap_ssid_prefix: FlightImpact
  ap_passphrase: flightimpact
  mdns_hostname: flightimpact

storage:
  db_path: /var/lib/flightimpact/shots.sqlite
  clip_dir: /var/lib/flightimpact/clips
  radar_dir: /var/lib/flightimpact/radar
  keep_clips_days: 30

api:
  host: 0.0.0.0
  port: 8000
  cors_origins:
    - "*"

dev_mode: true

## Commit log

2026-05-02 Add render_preview.py for matplotlib-based enclosure previews
    This script approximates the visual representation of the FlightImpact enclosure using matplotlib. It mirrors the parameters defined in params.scad without executing OpenSCAD, allowing for quick prev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
    [base.scad, dock.scad, params.scad]
2026-05-14 fix: update service user groups to include gpio and spi access
2026-05-15 feat: Refactor header to include settings modal and connection status
    - Added a settings modal to the header for easier access to configuration options.
    - Introduced a connection status pill to indicate device connectivity.
    - Updated header layout for improved visual hierarchy.
    feat: Create SettingsModal component for device settings
    - Implemented SettingsModal with calibration, app settings, and danger zone options.
    - Added functionality to close the modal with the Escape key and lock body scroll when open.
    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
2026-05-15 Refactor code structure for improved readability and maintainability
    [base.scad, base.stl, lid.scad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]
2026-05-17 feat: Implement low battery and sensor offline screens with alert logic
